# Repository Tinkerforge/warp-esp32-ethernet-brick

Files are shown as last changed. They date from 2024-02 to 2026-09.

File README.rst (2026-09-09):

WARP ESP32 Ethernet Brick
=========================

This repository contains the firmware source code and the hardware design
files. The documentation generator configs can be found at
https://github.com/Tinkerforge/generators

.. BEGIN WARP REPOSITORIES (managed block, generated from esp32-firmware/repo_overview.rst - do not edit by hand, run update_repo_overview.py instead)

WARP Repositories
-----------------

This is an overview of all repositories that make up the WARP Charger and
WARP Energy Manager ecosystem.

Please report **any** issue concerning WARP hard- or software in the
`esp32-firmware`_ repository, no matter which repository it originates from.

Software
~~~~~~~~

- `esp32-firmware`_ - Source code of the ESP32 firmware shared between all WARP Chargers and Energy Managers

Libraries used by the firmware:

- `tfjson`_ - SAX style JSON serializer and deserializer
- `tfnetwork`_ - Modbus TCP server and client implementation
- `tfocpp`_ - OCPP 1.6 implementation
- `tftools`_ - Miscellaneous tools and helpers

Remote access:

- `esp32-remote-access`_ - Source code of the my.warp-charger.com remote access server

Documentation, tools and integrations:

- `warp-charger`_ - Source code of (docs.)warp-charger.com and the printed manual, released firmwares, datasheets and documents, as well as some tools and hardware design files
- `api.warp-charger.com`_ - Serves APIs that are used by WARP Chargers to obtain relevant public information like day ahead prices
- `vislog.warp-charger.com`_ - Visualizes WARP Charger logs and EVSE debug protocols
- `dbus-warp-charger`_ - Integrates WARP Chargers into a Victron Energy Venus OS device (e.g. Cerbo GX)

WARP Charger Hardware
~~~~~~~~~~~~~~~~~~~~~~

WARP4 Charger
"""""""""""""

*Current charger generation.*

- `warp-esp32-ethernet-v2-brick`_ - Hardware design files of the WARP ESP32 Ethernet Brick 2.0
- `warp-esp32-ethernet-v2-co-bricklet`_ - Firmware source code of the WARP ESP32 Ethernet 2.0 Co Bricklet (co-processor)
- `evse-v4-bricklet`_ - Hardware design files of the EVSE 4.0 Bricklet (firmware shared with the EVSE 2.0 Bricklet)
- `nfc-bricklet`_ - Firmware source code and hardware design files of the NFC Bricklet

WARP3 Charger
"""""""""""""

- `warp-esp32-ethernet-brick`_ - Hardware design files of the WARP ESP32 Ethernet Brick
- `evse-v3-bricklet`_ - Hardware design files of the EVSE 3.0 Bricklet (firmware shared with the EVSE 2.0 Bricklet)
- `nfc-bricklet`_ - Firmware source code and hardware design files of the NFC Bricklet

WARP2 Charger
"""""""""""""

- `esp32-ethernet-brick`_ - Hardware design files of the ESP32 Ethernet Brick
- `evse-v2-bricklet`_ - Firmware source code and hardware design files of the EVSE 2.0 Bricklet
- `nfc-bricklet`_ - Firmware source code and hardware design files of the NFC Bricklet

WARP1 Charger
"""""""""""""

- `esp32-brick`_ - Hardware design files of the ESP32 Brick
- `evse-bricklet`_ - Firmware source code and hardware design files of the EVSE Bricklet
- `rs485-bricklet`_ - Firmware source code and hardware design files of the RS485 Bricklet

WARP Energy Manager Hardware
~~~~~~~~~~~~~~~~~~~~~~~~~~~~~~

WARP Energy Manager 2.0
"""""""""""""""""""""""

*Current energy manager generation.*

- `esp32-ethernet-brick`_ - Hardware design files of the ESP32 Ethernet Brick
- `warp-energy-manager-v2-bricklet`_ - Firmware source code and hardware design files of the WARP Energy Manager 2.0 Bricklet
- `warp-front-panel-bricklet`_ - Firmware source code and hardware design files of the WARP Front Panel Bricklet

WARP Energy Manager 1.0
"""""""""""""""""""""""

- `esp32-ethernet-brick`_ - Hardware design files of the ESP32 Ethernet Brick
- `warp-energy-manager-bricklet`_ - Firmware source code and hardware design files of the WARP Energy Manager Bricklet

Forked/patched projects
~~~~~~~~~~~~~~~~~~~~~~~~~

- `arduino-esp32`_
- `esp32-arduino-libs`_
- `WireGuard-ESP32-Arduino`_

.. Link targets: One definition per repository, keep in sync with the lists above.

.. _esp32-firmware: https://github.com/Tinkerforge/esp32-firmware
.. _tfjson: https://github.com/Tinkerforge/tfjson
.. _tfnetwork: https://github.com/Tinkerforge/tfnetwork
.. _tfocpp: https://github.com/Tinkerforge/tfocpp
.. _tftools: https://github.com/Tinkerforge/tftools
.. _esp32-remote-access: https://github.com/Tinkerforge/esp32-remote-access
.. _warp-charger: https://github.com/Tinkerforge/warp-charger
.. _api.warp-charger.com: https://github.com/Tinkerforge/api.warp-charger.com
.. _vislog.warp-charger.com: https://github.com/Tinkerforge/vislog.warp-charger.com
.. _dbus-warp-charger: https://github.com/Tinkerforge/dbus-warp-charger
.. _warp-esp32-ethernet-v2-brick: https://github.com/Tinkerforge/warp-esp32-ethernet-v2-brick
.. _warp-esp32-ethernet-v2-co-bricklet: https://github.com/Tinkerforge/warp-esp32-ethernet-v2-co-bricklet
.. _evse-v4-bricklet: https://github.com/Tinkerforge/evse-v4-bricklet
.. _nfc-bricklet: https://github.com/Tinkerforge/nfc-bricklet
.. _warp-esp32-ethernet-brick: https://github.com/Tinkerforge/warp-esp32-ethernet-brick
.. _evse-v3-bricklet: https://github.com/Tinkerforge/evse-v3-bricklet
.. _esp32-ethernet-brick: https://github.com/Tinkerforge/esp32-ethernet-brick
.. _evse-v2-bricklet: https://github.com/Tinkerforge/evse-v2-bricklet
.. _esp32-brick: https://github.com/Tinkerforge/esp32-brick
.. _evse-bricklet: https://github.com/Tinkerforge/evse-bricklet
.. _rs485-bricklet: https://github.com/Tinkerforge/rs485-bricklet
.. _warp-energy-manager-v2-bricklet: https://github.com/Tinkerforge/warp-energy-manager-v2-bricklet
.. _warp-front-panel-bricklet: https://github.com/Tinkerforge/warp-front-panel-bricklet
.. _warp-energy-manager-bricklet: https://github.com/Tinkerforge/warp-energy-manager-bricklet
.. _arduino-esp32: https://github.com/Tinkerforge/arduino-esp32
.. _esp32-arduino-libs: https://github.com/Tinkerforge/esp32-arduino-libs
.. _WireGuard-ESP32-Arduino: https://github.com/Tinkerforge/WireGuard-ESP32-Arduino

.. END WARP REPOSITORIES

Repository Content
------------------

hardware/:
 * Contains KiCad project files and additionally schematics as PDF

datasheets/:
 * Contains datasheets for sensors and complex ICs that are used

Hardware
--------

The hardware is designed with the open source EDA Suite KiCad
(http://www.kicad.org). Before you are able to open the files,
you have to install the Tinkerforge kicad-libraries
(https://github.com/Tinkerforge/kicad-libraries). You can either clone
them directly in hardware/ or clone them in a separate folder and
symlink them into hardware/
(ln -s kicad_path/kicad-libraries project_path/hardware). After that you
can open the .pro file in hardware/ with KiCad and from there view and
modify the schematics and the PCB layout.

Software
--------

The software for all Bricks based on the ESP32 can be found at:
https://github.com/Tinkerforge/esp32-firmware/tree/master/software

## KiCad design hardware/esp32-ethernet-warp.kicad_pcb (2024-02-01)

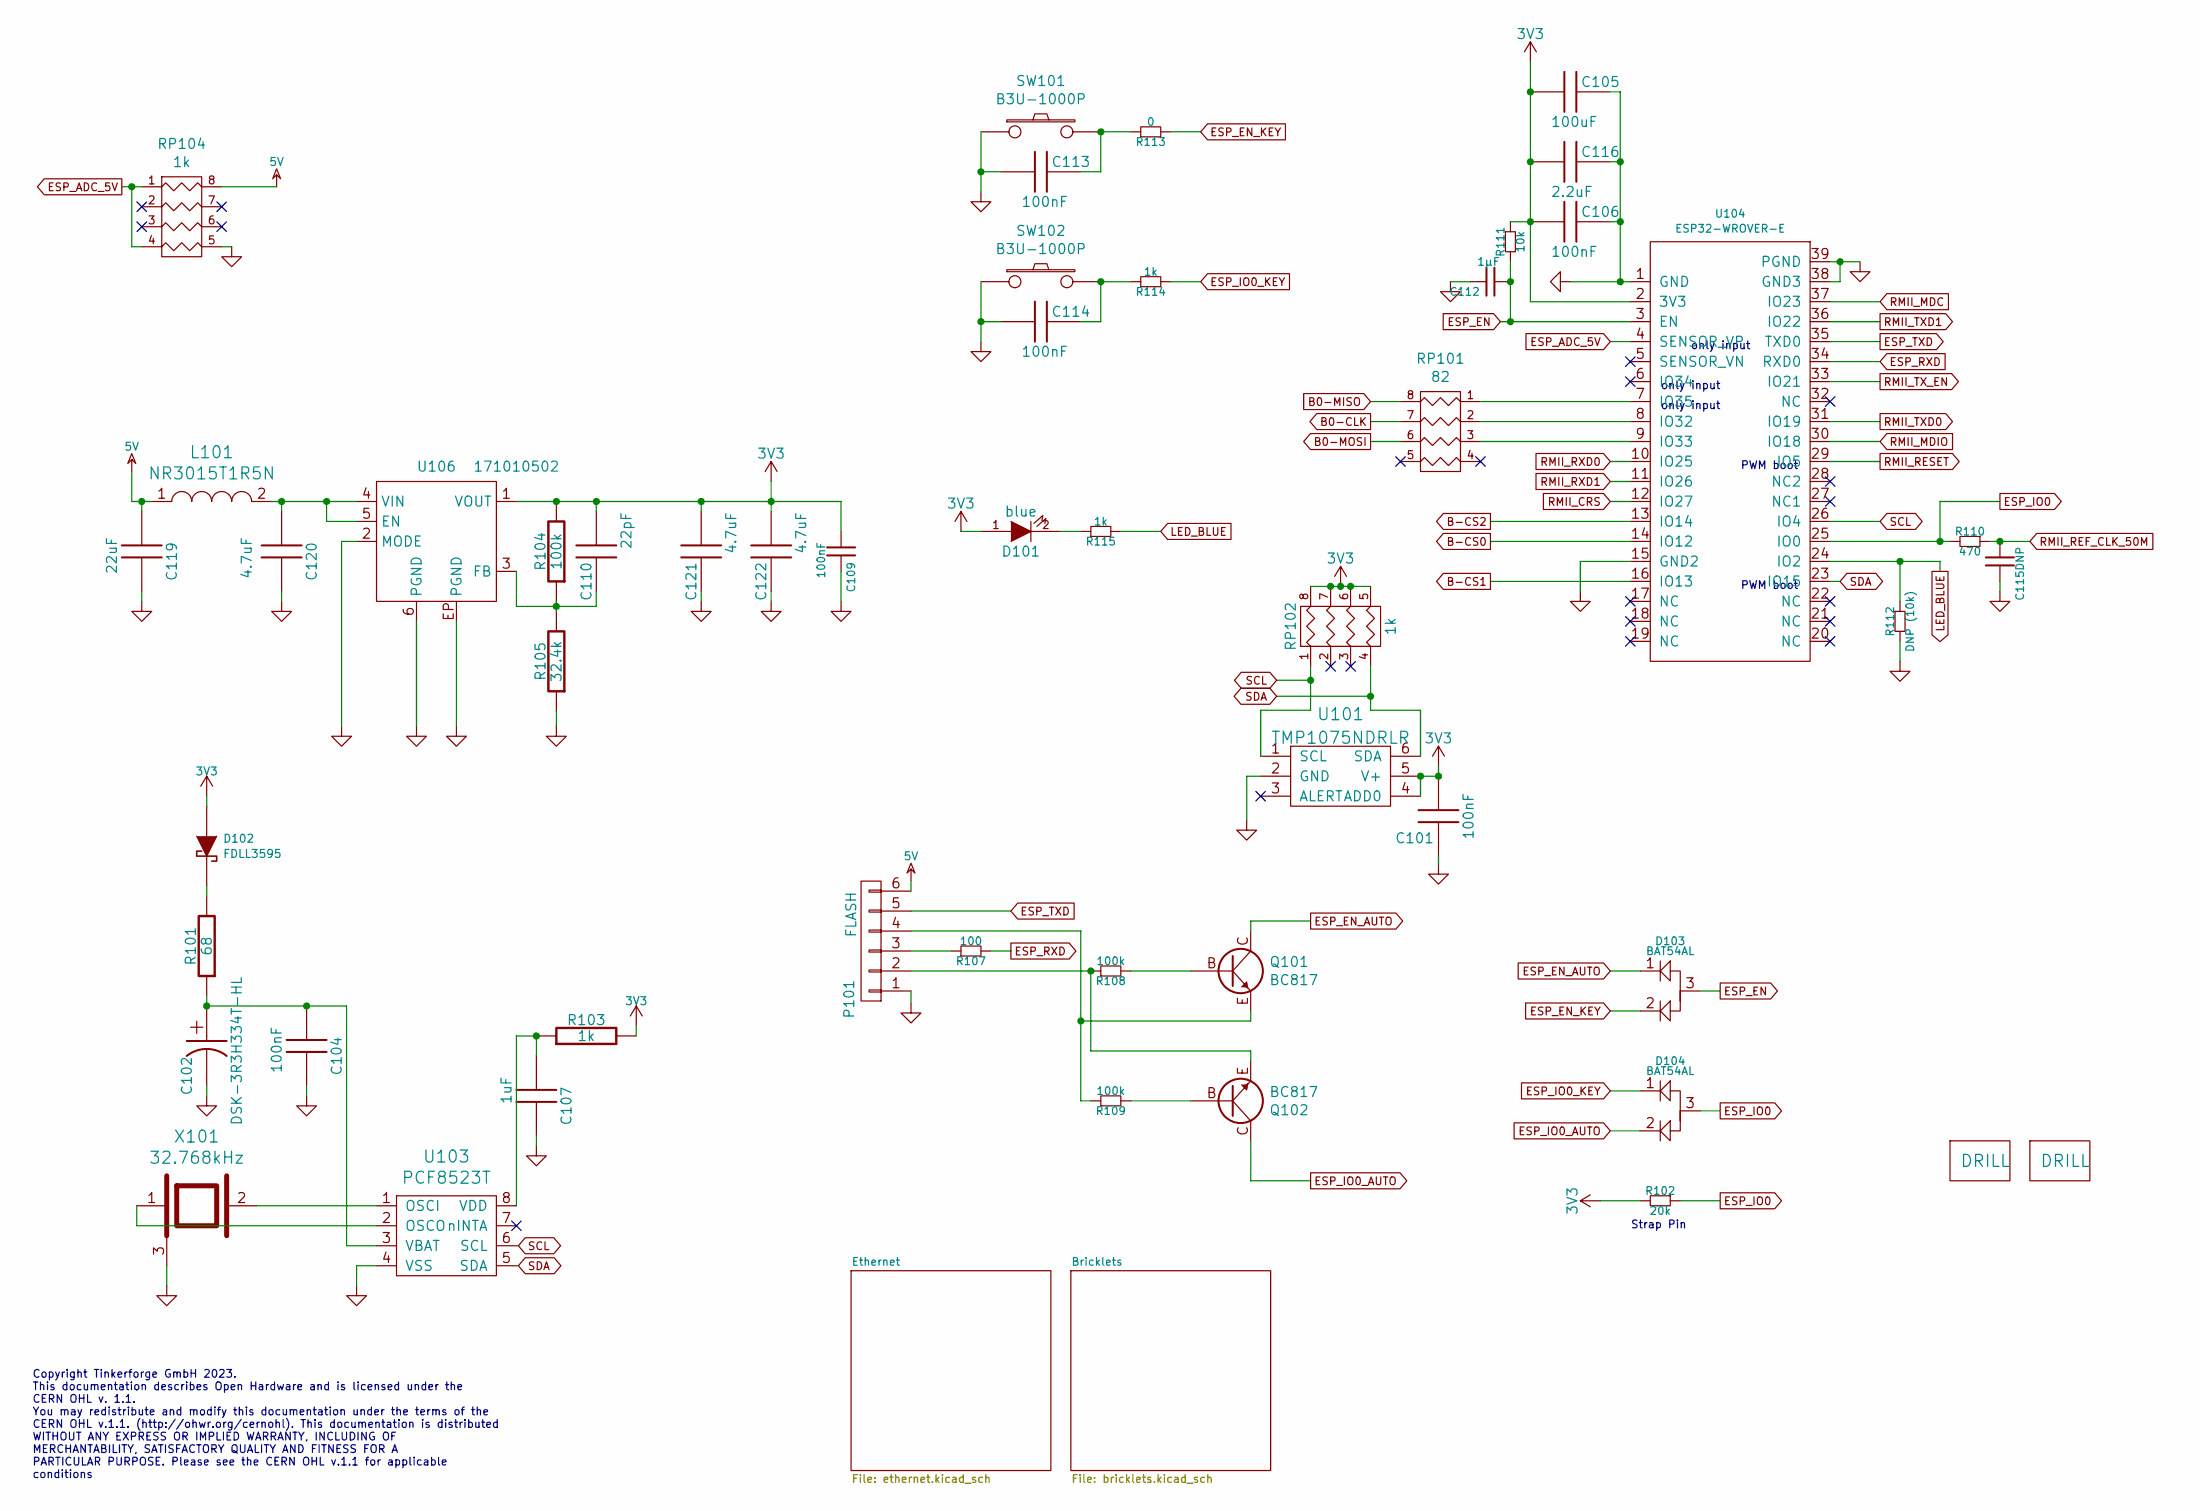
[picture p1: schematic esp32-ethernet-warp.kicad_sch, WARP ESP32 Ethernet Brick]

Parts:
C101, C104, C106, C109, C113, C114: 100nF; C0402F
C102: DSK-3R3H334T-HL; DSK
C105: 100uF; C1210
C107: 1uF; C0603F
C110: 22pF; C0402F
C112: 1µF; C0603F
C115: DNP; C0402F
C116: 2.2uF; C0603F
C119: 22uF; C1206
C120, C121, C122: 4.7uF; C0805E
D101: blue; D0603F
D102: FDLL3595; MiniMelf
D103, D104: BAT54AL; SOT23-3
F102, F103: DRILL; LSMTSO-M3
L101: NR3015T1R5N; NR3030
P101: FLASH; pin_array_1x6-P2mm_D1mm
Q101, Q102: BC817; SOT23EBC
R101: 68; R0402F
R102: 20k; R0402F
R103, R114, R115: 1k; R0402F
R104, R108, R109: 100k; R0402F
R105: 32.4k; R0402F
R107: 100; R0402F
R110: 470; R0402F
R111: 10k; R0402F
R112: DNP (10k); R0402F
R113: 0; R0402F
RP101: 82; 4X0402
RP102, RP104: 1k; 4X0402
SW101, SW102: B3U-1000P
U101: TMP1075NDRLR; SOT563
U103: PCF8523T; SO-8
U104: ESP32-WROVER-E
U106: 171010502
X101: 32.768kHz; AB26TRQ

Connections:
3V3: C101.1, C105.2, C106.2, C109.2, C110.2, C116.2, C121.2, C122.2, D101.1 (A), D102.1 (A), R102.2, R103.2, R104.2, R111.1, RP102.5 (R4), RP102.6 (R3), RP102.7 (R2), RP102.8 (R1), U101.4 (ADD0), U101.5 (V+), U104.2 (3V3), U106.1 (VOUT); also elsewhere on the board
5V: C119.2, L101.1, P101.6, RP104.8 (R1); also elsewhere on the board
B0-CLK: RP101.7 (R2); also elsewhere on the board
B0-MISO: RP101.8 (R1); also elsewhere on the board
B0-MOSI: RP101.6 (R3); also elsewhere on the board
B-CS0: U104.14 (IO12); also elsewhere on the board
B-CS1: U104.16 (IO13); also elsewhere on the board
B-CS2: U104.13 (IO14); also elsewhere on the board
ESP_ADC_5V: RP104.1, RP104.4, U104.4 (SENSOR_VP)
ESP_EN: C112.2, D103.3, R111.2, U104.3 (EN)
ESP_EN_AUTO: D103.1, Q101.C
ESP_EN_KEY: D103.2, R113.2
ESP_IO0: D104.3, R102.1, R110.2, U104.25 (IO0)
ESP_IO0_AUTO: D104.2, Q102.C
ESP_IO0_KEY: D104.1, R114.2
ESP_RXD: R107.2, U104.34 (RXD0)
ESP_TXD: P101.5, U104.35 (TXD0)
GND: C101.2, C102.2, C104.1, C105.1, C106.1, C107.1, C109.1, C112.1, C113.2, C114.2, C115.2, C116.1, C119.1, C120.1, C121.1, C122.1, P101.1, R105.1, R112.2, RP104.5 (R4), SW101.1, SW102.1, U101.2 (GND), U103.4 (VSS), U104.1 (GND), U104.15 (GND2), U104.38 (GND3), U104.39 (PGND), U106.2 (MODE), U106.6 (PGND), U106.EP (PGND), X101.3; also elsewhere on the board
LED_BLUE: R112.1, R115.2, U104.24 (IO2)
unnamed: C113.1, R113.1, SW101.2
unnamed: C114.1, R114.1, SW102.2
unnamed: D101.2 (K), R115.1
unnamed: D102.2 (K), R101.2
unnamed: P101.2, Q102.E, R108.1
unnamed: P101.3, R107.1
unnamed: P101.4, Q101.E, R109.1
unnamed: Q101.B, R108.2
unnamed: Q102.B, R109.2
unnamed: RP101.1, U104.7 (IO35)
unnamed: RP101.2, U104.8 (IO32)
unnamed: RP101.3, U104.9 (IO33)
unnamed: U103.1 (OSCI), X101.2
unnamed: U103.2 (OSCO), X101.1
unnamed: C102.1, C104.2, R101.1, U103.3 (VBAT)
unnamed: C107.2, R103.1, U103.8 (VDD)
unnamed: C120.2, L101.2, U106.4 (VIN), U106.5 (EN)
unnamed: C110.1, R104.1, R105.2, U106.3 (FB)
RMII_CRS: U104.12 (IO27); also elsewhere on the board
RMII_MDC: U104.37 (IO23); also elsewhere on the board
RMII_MDIO: U104.30 (IO18); also elsewhere on the board
RMII_REF_CLK_50M: C115.1, R110.1; also elsewhere on the board
RMII_RESET: U104.29 (IO5); also elsewhere on the board
RMII_RXD0: U104.10 (IO25); also elsewhere on the board
RMII_RXD1: U104.11 (IO26); also elsewhere on the board
RMII_TXD0: U104.31 (IO19); also elsewhere on the board
RMII_TXD1: U104.36 (IO22); also elsewhere on the board
RMII_TX_EN: U104.33 (IO21); also elsewhere on the board
SCL: RP102.1, U101.1 (SCL), U103.6 (SCL), U104.26 (IO4)
SDA: RP102.4, U101.6 (SDA), U103.5 (SDA), U104.23 (IO15)

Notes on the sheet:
Strap Pin
only input
Copyright Tinkerforge GmbH 2023. This documentation describes Open Hardware and is licensed under the CERN OHL v. 1.1. You may redistribute and modify this documentation under the terms of the CERN OHL v.1.1. (http://ohwr.org/cernohl). This documentation is distributed WITHOUT ANY EXPRESS OR IMPLIE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
PWM boot

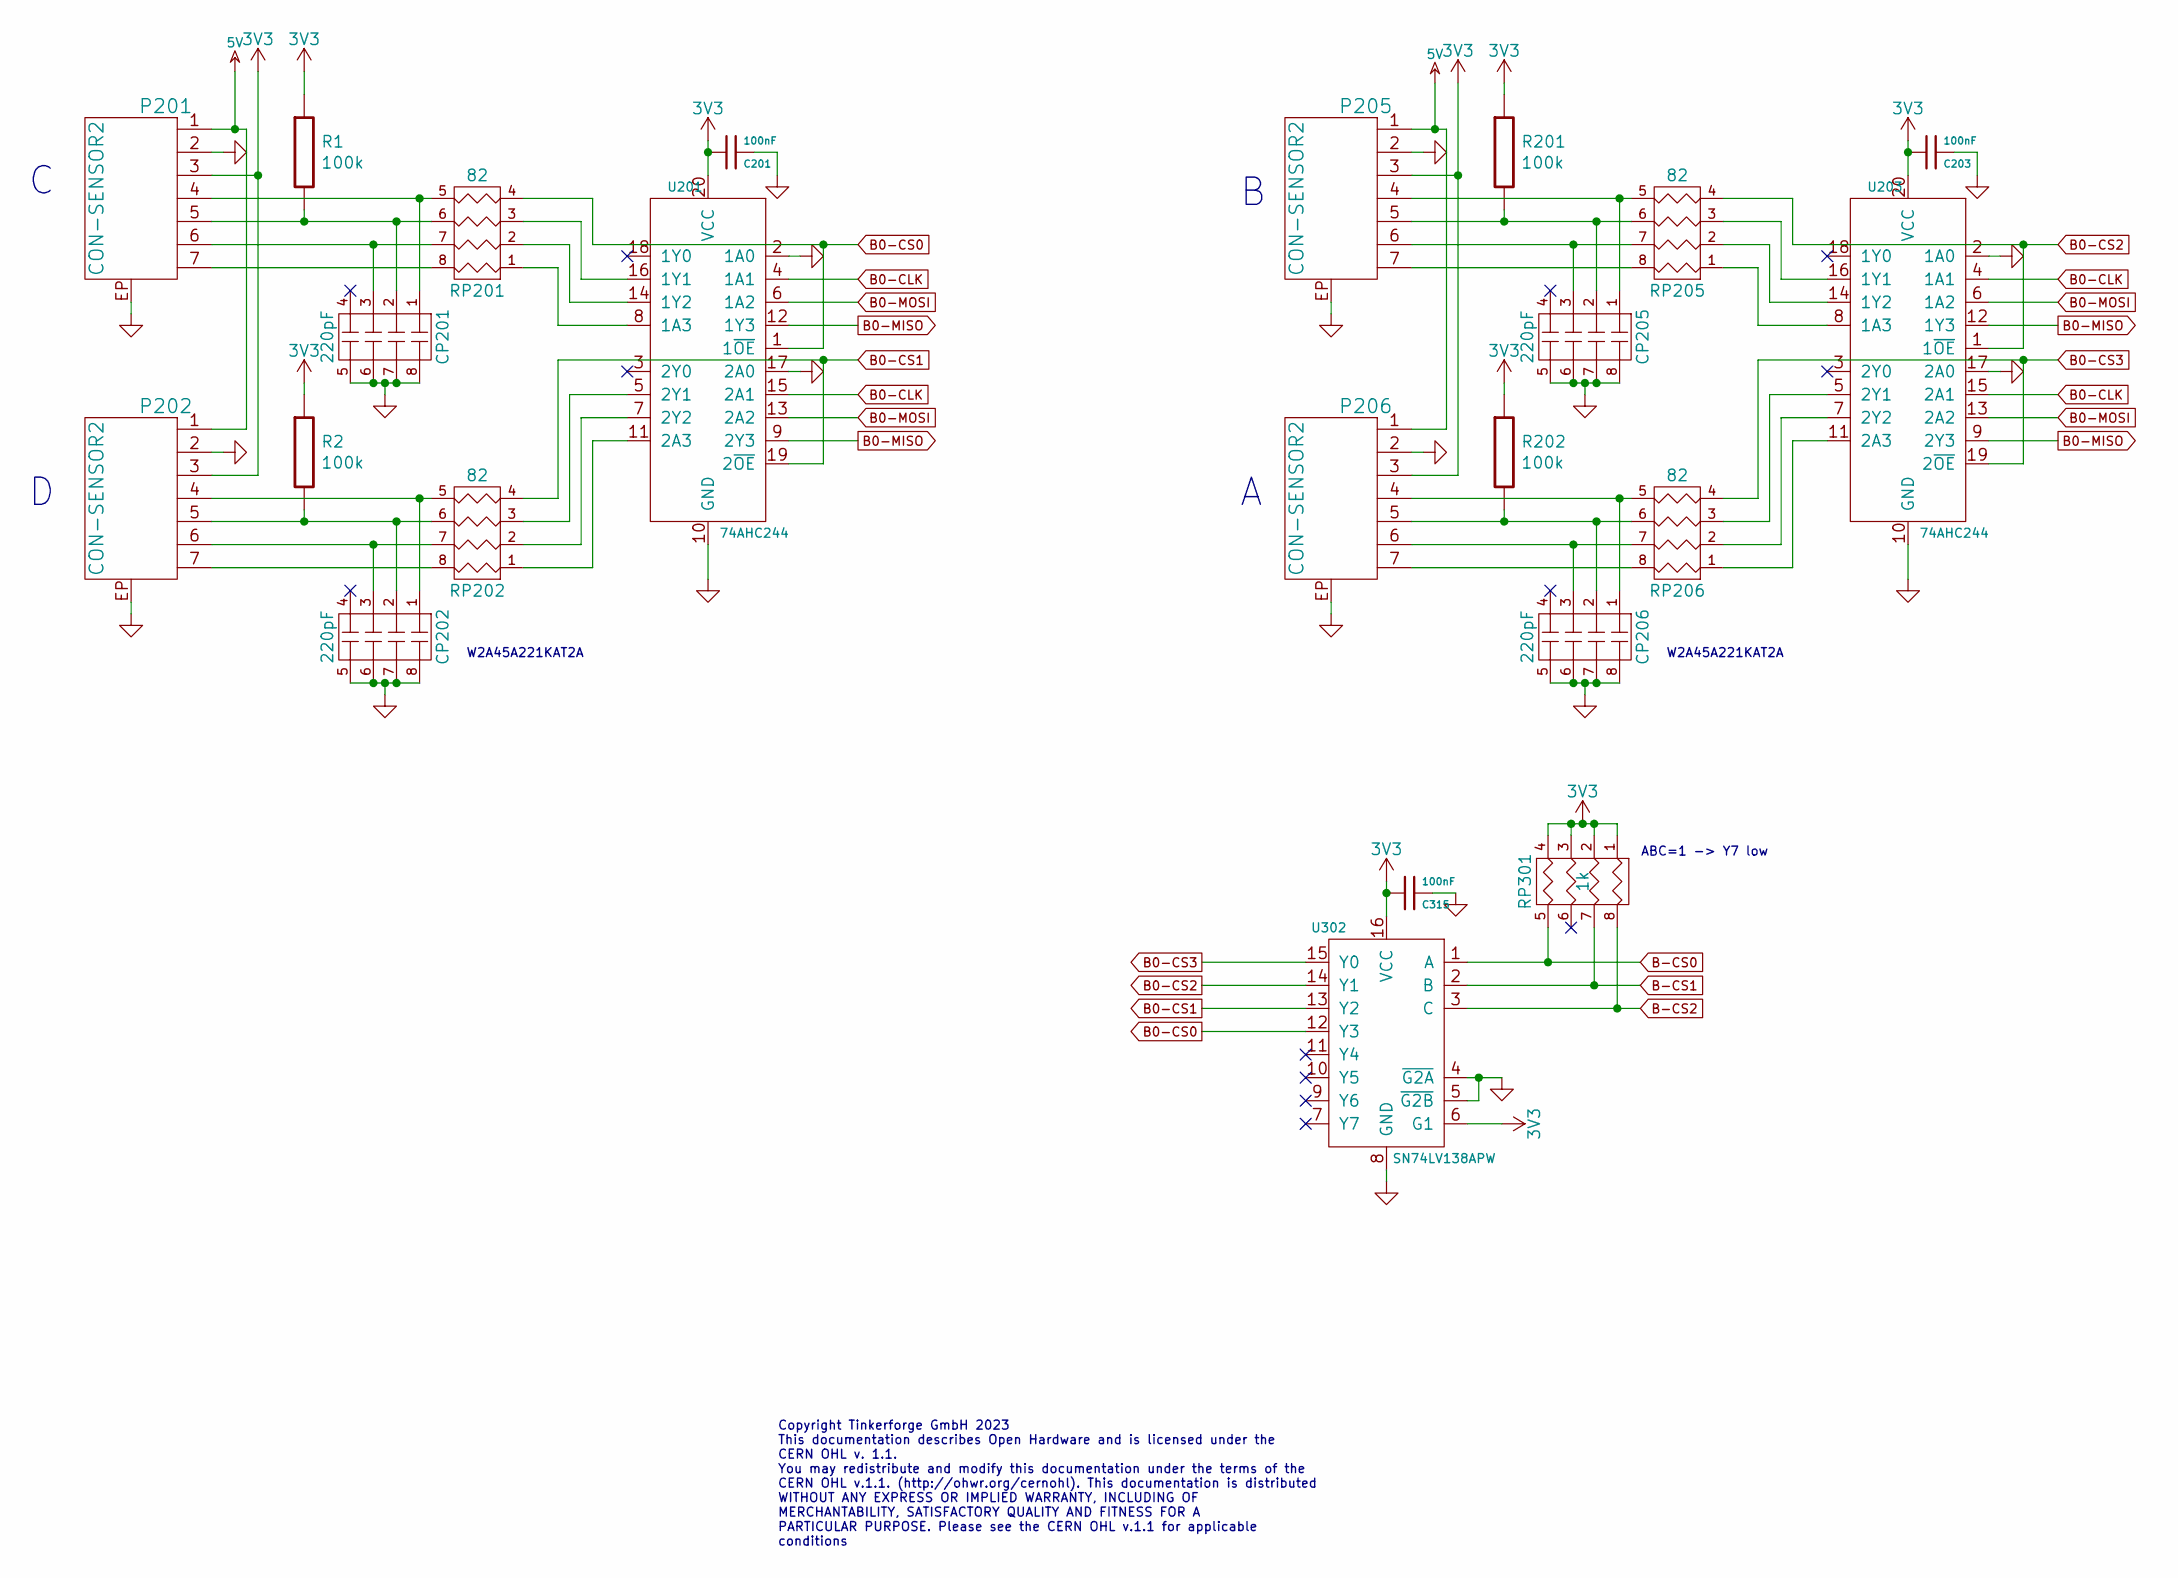
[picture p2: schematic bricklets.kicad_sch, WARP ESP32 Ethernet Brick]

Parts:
C201, C203, C315: 100nF; C0402F
CP201, CP202, CP205, CP206: 220pF; 4X0402
P201, P202, P205, P206: CON-SENSOR2
R1, R2, R201, R202: 100k; R0402F
RP201, RP202, RP205, RP206: 82; 4X0402
RP301: 1k; 4X0402
U201, U203: 74AHC244; TSSOP20
U302: SN74LV138APW; TSSOP16

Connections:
3V3: C201.2, C203.2, C315.2, P201.3, P202.3, P205.3, P206.3, R1.1, R2.1, R201.1, R202.1, RP301.1, RP301.2, RP301.3, RP301.4, U201.20 (VCC), U203.20 (VCC), U302.6 (G1), U302.16 (VCC); also elsewhere on the board
5V: P201.1, P202.1, P205.1, P206.1; also elsewhere on the board
B0-CLK: U201.4 (1A1), U201.15 (2A1), U203.4 (1A1), U203.15 (2A1); also elsewhere on the board
B0-CS0: RP201.4, U201.1 (1~OE), U302.12 (Y3)
B0-CS1: RP202.4, U201.19 (2~OE), U302.13 (Y2)
B0-CS2: RP205.4, U203.1 (1~OE), U302.14 (Y1)
B0-CS3: RP206.4, U203.19 (2~OE), U302.15 (Y0)
B0-MISO: U201.9 (2Y3), U201.12 (1Y3), U203.9 (2Y3), U203.12 (1Y3); also elsewhere on the board
B0-MOSI: U201.6 (1A2), U201.13 (2A2), U203.6 (1A2), U203.13 (2A2); also elsewhere on the board
B-CS0: RP301.5 (R4), U302.1 (A); also elsewhere on the board
B-CS1: RP301.7 (R2), U302.2 (B); also elsewhere on the board
B-CS2: RP301.8 (R1), U302.3 (C); also elsewhere on the board
GND: C201.1, C203.1, C315.1, CP201.5 (R4), CP201.6 (R3), CP201.7 (R2), CP201.8 (R1), CP202.5 (R4), CP202.6 (R3), CP202.7 (R2), CP202.8 (R1), CP205.5 (R4), CP205.6 (R3), CP205.7 (R2), CP205.8 (R1), CP206.5 (R4), CP206.6 (R3), CP206.7 (R2), CP206.8 (R1), P201.2, P201.EP, P202.2, P202.EP, P205.2, P205.EP, P206.2, P206.EP, U201.2 (1A0), U201.10 (GND), U201.17 (2A0), U203.2 (1A0), U203.10 (GND), U203.17 (2A0), U302.4 (~G2A), U302.5 (~G2B), U302.8 (GND); also elsewhere on the board
unnamed: CP201.1, P201.4, RP201.5 (R4)
unnamed: CP201.2, P201.5, R1.2, RP201.6 (R3)
unnamed: CP201.3, P201.6, RP201.7 (R2)
unnamed: CP202.1, P202.4, RP202.5 (R4)
unnamed: CP202.2, P202.5, R2.2, RP202.6 (R3)
unnamed: CP202.3, P202.6, RP202.7 (R2)
unnamed: CP205.1, P205.4, RP205.5 (R4)
unnamed: CP205.2, P205.5, R201.2, RP205.6 (R3)
unnamed: CP205.3, P205.6, RP205.7 (R2)
unnamed: CP206.1, P206.4, RP206.5 (R4)
unnamed: CP206.2, P206.5, R202.2, RP206.6 (R3)
unnamed: CP206.3, P206.6, RP206.7 (R2)
unnamed: RP201.1, U201.8 (1A3)
unnamed: RP201.2, U201.14 (1Y2)
unnamed: RP201.3, U201.16 (1Y1)
unnamed: P201.7, RP201.8 (R1)
unnamed: RP202.1, U201.11 (2A3)
unnamed: RP202.2, U201.7 (2Y2)
unnamed: RP202.3, U201.5 (2Y1)
unnamed: P202.7, RP202.8 (R1)
unnamed: RP205.1, U203.8 (1A3)
unnamed: RP205.2, U203.14 (1Y2)
unnamed: RP205.3, U203.16 (1Y1)
unnamed: P205.7, RP205.8 (R1)
unnamed: RP206.1, U203.11 (2A3)
unnamed: RP206.2, U203.7 (2Y2)
unnamed: RP206.3, U203.5 (2Y1)
unnamed: P206.7, RP206.8 (R1)

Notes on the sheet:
Copyright Tinkerforge GmbH 2023 This documentation describes Open Hardware and is licensed under the CERN OHL v. 1.1. You may redistribute and modify this documentation under the terms of the CERN OHL v.1.1. (http://ohwr.org/cernohl). This documentation is distributed WITHOUT ANY EXPRESS OR IMPLIED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
W2A45A221KAT2A
ABC=1 -> Y7 low

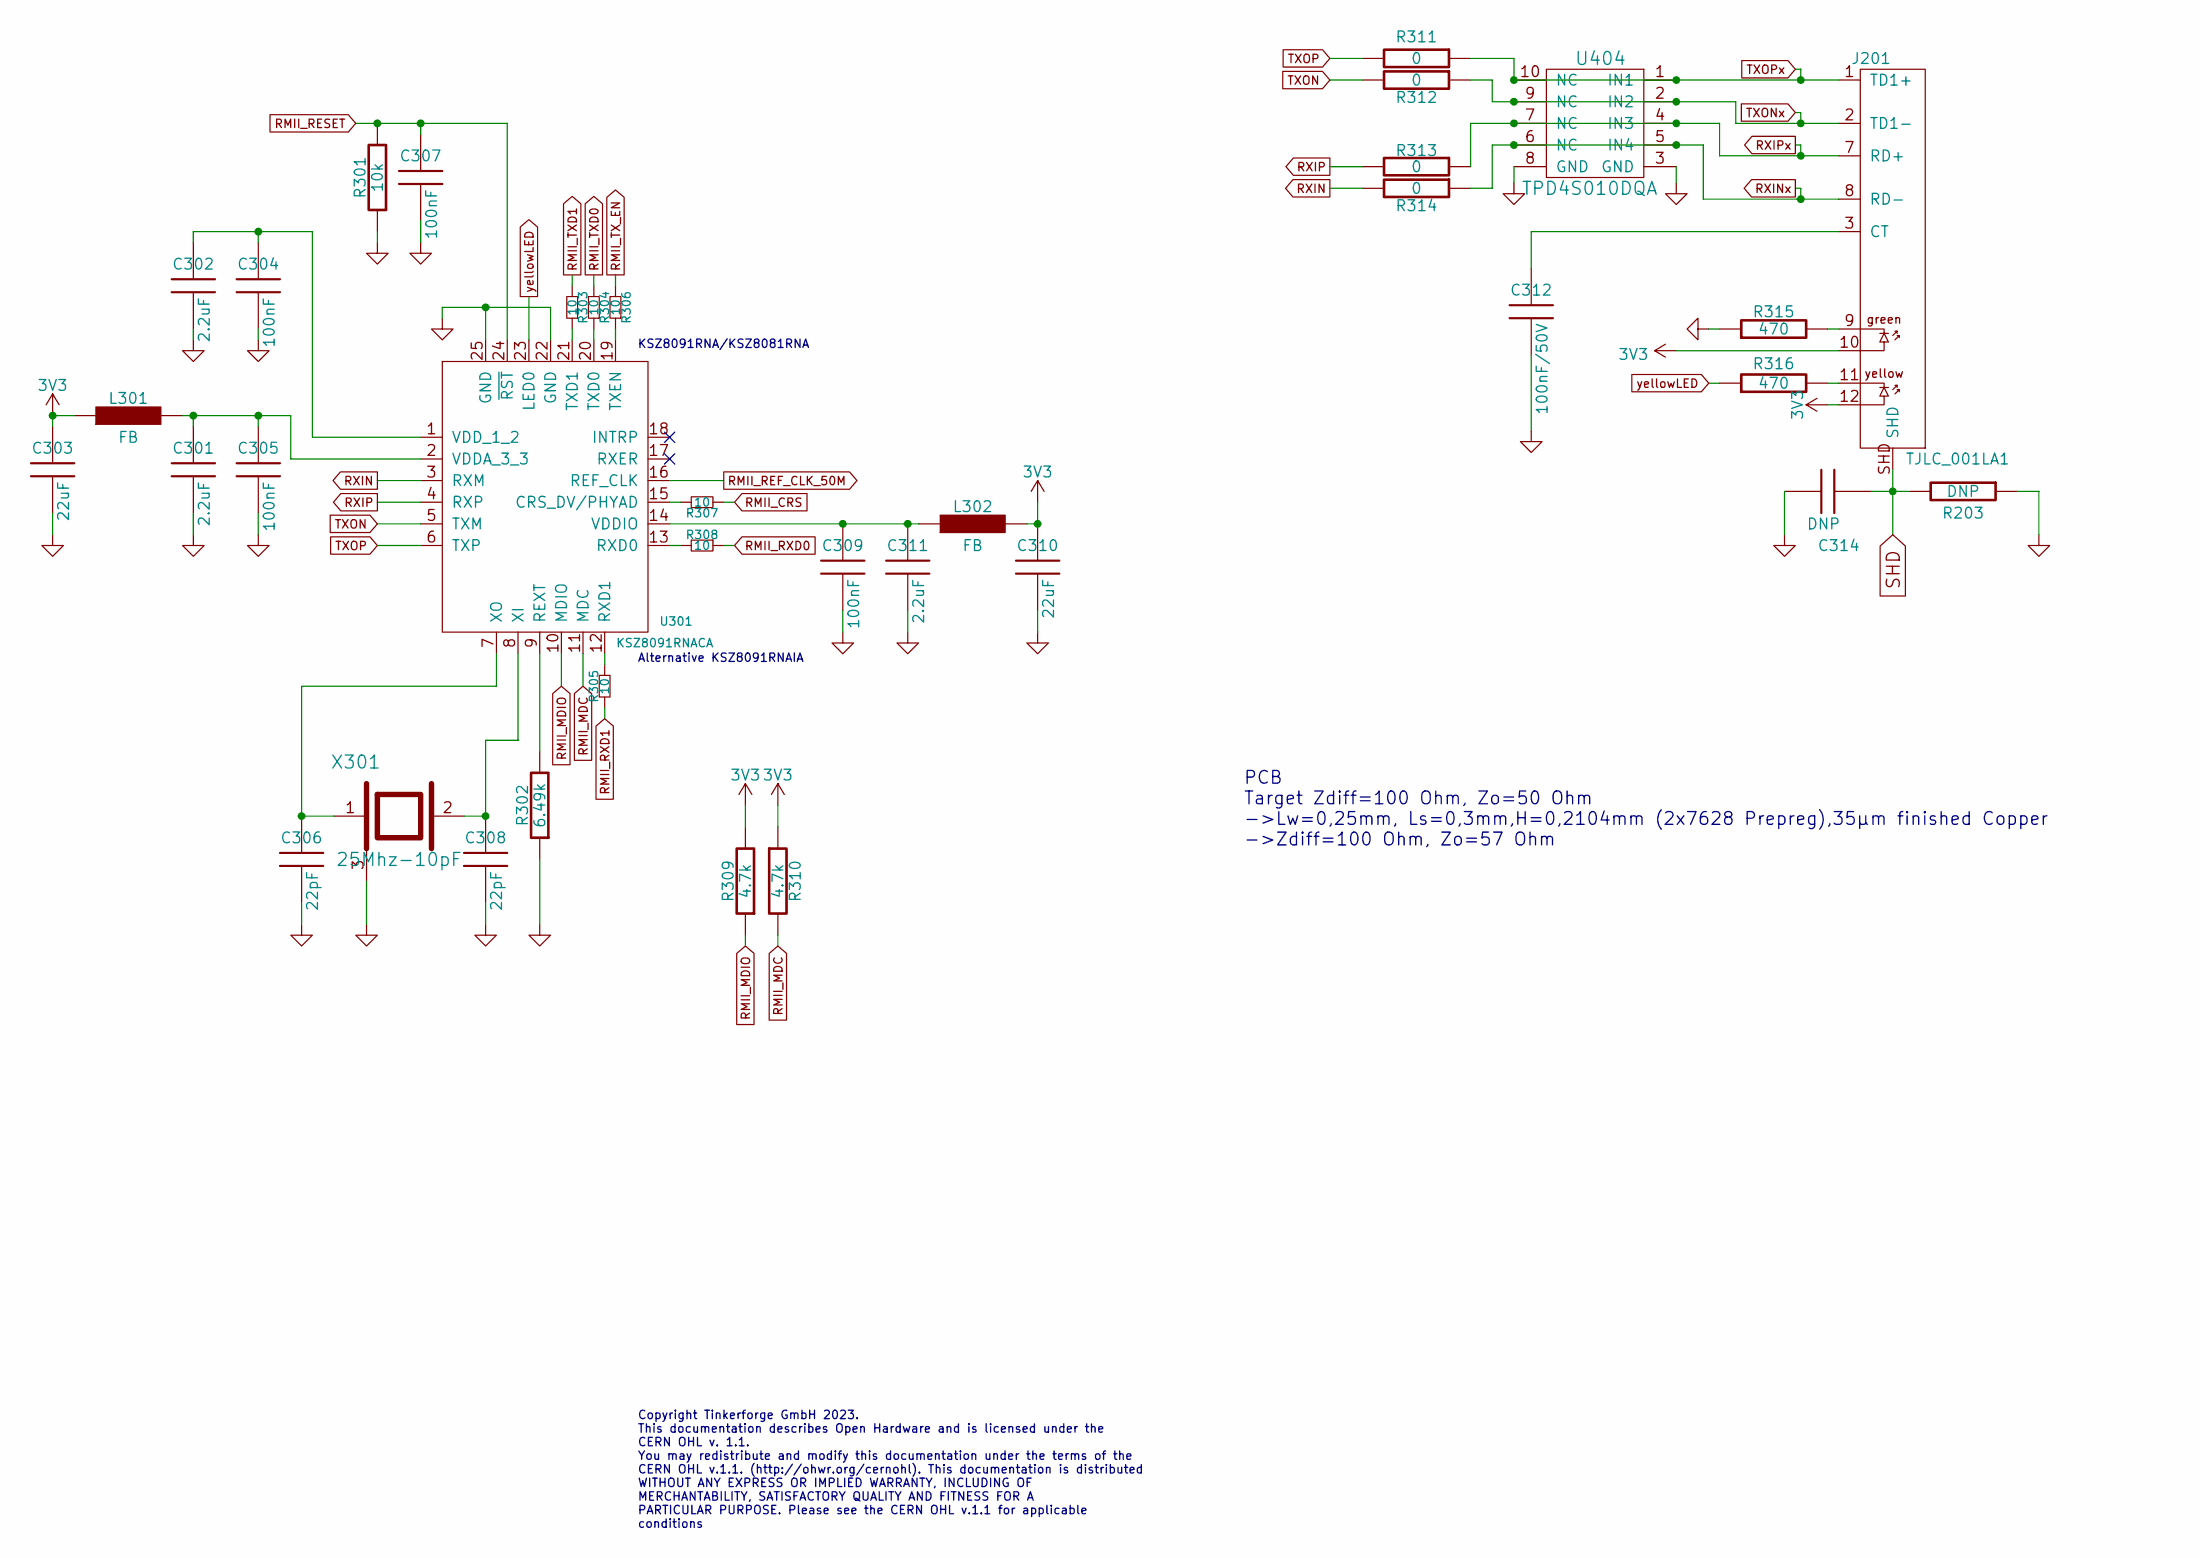
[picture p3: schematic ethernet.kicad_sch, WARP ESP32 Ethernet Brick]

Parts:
C301, C302, C311: 2.2uF; C0603F
C303, C310: 22uF; C1206
C304, C305, C307, C309: 100nF; C0402F
C306, C308: 22pF; C0402F
C312: 100nF/50V; C0402F
C314: DNP; C1206
J201: TJLC_001LA1; TJLC-001LA1
L301, L302: FB; R0603F
R203: DNP; 1812
R301: 10k; R0402F
R302: 6.49k; R0402F
R303, R304, R305, R306, R307, R308: 10; R0402F
R309, R310: 4.7k; R0402F
R311, R312, R313, R314: 0; R0402F
R315, R316: 470; R0402F
U301: KSZ8091RNACA; QFN-24-4x4-EP
U404: TPD4S010DQA
X301: 25Mhz-10pF; CRYSTAL_3225

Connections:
3V3: C303.2, C310.2, J201.10, J201.12, L301.1, L302.2, R309.2, R310.1; also elsewhere on the board
GND: C301.1, C302.1, C303.1, C304.1, C305.1, C306.1, C307.1, C308.1, C309.1, C310.1, C311.1, C312.1, C314.2, R203.1, R301.1, R302.1, R315.1, U301.22 (GND), U301.25 (GND), X301.3; also elsewhere on the board
unnamed: C312.2, J201.3 (CT)
unnamed: J201.9, R315.2
unnamed: J201.11, R316.2
unnamed: R307.1, U301.15 (CRS_DV/PHYAD)
unnamed: R302.2, U301.9 (REXT)
unnamed: R308.2, U301.13 (RXD0)
unnamed: R305.1, U301.12 (RXD1)
unnamed: R304.1, U301.20 (TXD0)
unnamed: R303.1, U301.21 (TXD1)
unnamed: R306.1, U301.19 (TXEN)
unnamed: C301.2, C305.2, L301.2, U301.2 (VDDA_3_3)
unnamed: C309.2, C311.2, L302.1, U301.14 (VDDIO)
unnamed: C302.2, C304.2, U301.1 (VDD_1_2)
unnamed: C308.2, U301.8 (XI), X301.2
unnamed: C306.2, U301.7 (XO), X301.1
RMII_CRS: R307.2; also elsewhere on the board
RMII_MDC: R310.2, U301.11 (MDC); also elsewhere on the board
RMII_MDIO: R309.1, U301.10 (MDIO); also elsewhere on the board
RMII_REF_CLK_50M: U301.16 (REF_CLK); also elsewhere on the board
RMII_RESET: C307.2, R301.2, U301.24 (~RST); also elsewhere on the board
RMII_RXD0: R308.1; also elsewhere on the board
RMII_RXD1: R305.2; also elsewhere on the board
RMII_TXD0: R304.2; also elsewhere on the board
RMII_TXD1: R303.2; also elsewhere on the board
RMII_TX_EN: R306.2; also elsewhere on the board
RXIN: R314.2, U301.3 (RXM)
RXINx: J201.8 (RD-), R314.1; also elsewhere on the board
RXIP: R313.2, U301.4 (RXP)
RXIPx: J201.7 (RD+), R313.1; also elsewhere on the board
SHD: C314.1, J201.SHD, R203.2
TXON: R312.2, U301.5 (TXM)
TXONx: J201.2 (TD1-), R312.1; also elsewhere on the board
TXOP: R311.2, U301.6 (TXP)
TXOPx: J201.1 (TD1+), R311.1; also elsewhere on the board
yellowLED: R316.1, U301.23 (LED0)

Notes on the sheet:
KSZ8091RNA/KSZ8081RNA
PCB Target Zdiff=100 Ohm, Zo=50 Ohm ->Lw=0,25mm, Ls=0,3mm,H=0,2104mm (2x7628 Prepreg),35µm finished Copper ->Zdiff=100 Ohm, Zo=57 Ohm
Alternative KSZ8091RNAIA
Copyright Tinkerforge GmbH 2023. This documentation describes Open Hardware and is licensed under the CERN OHL v. 1.1. You may redistribute and modify this documentation under the terms of the CERN OHL v.1.1. (http://ohwr.org/cernohl). This documentation is distributed WITHOUT ANY EXPRESS OR IMPLIE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

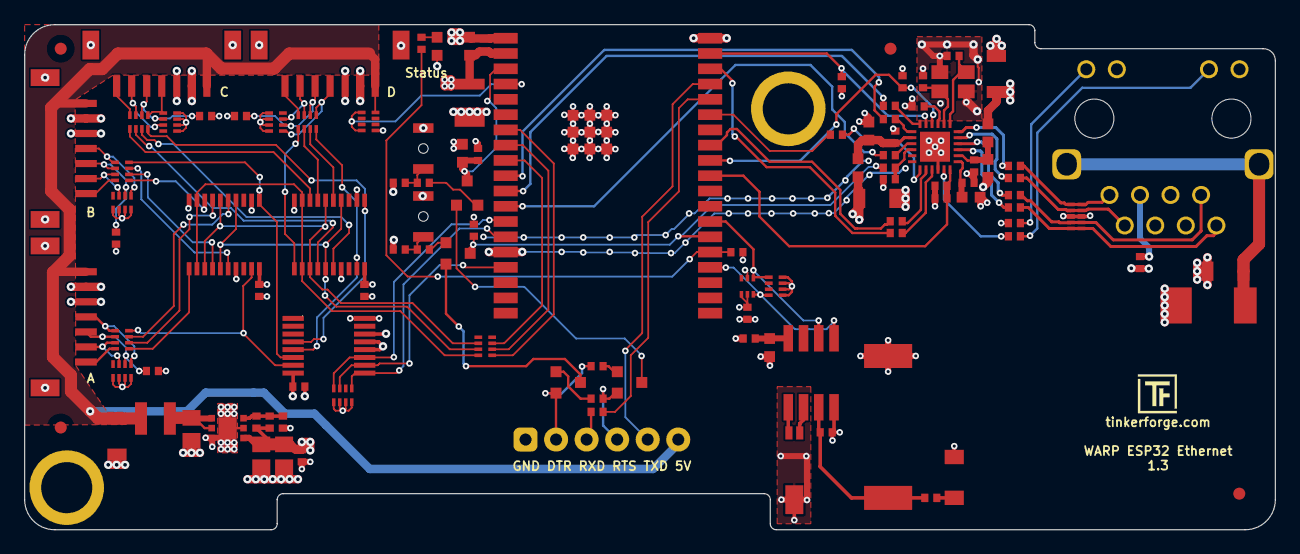
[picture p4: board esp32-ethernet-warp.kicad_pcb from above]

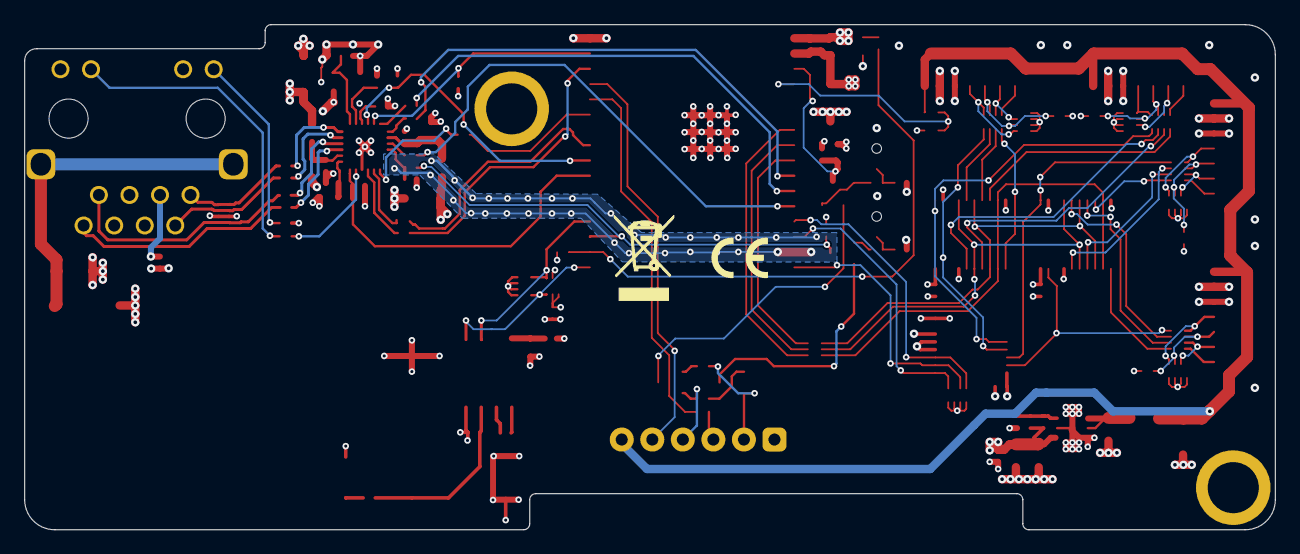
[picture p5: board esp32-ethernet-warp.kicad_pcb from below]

Board: 4 copper layers, 104.0 x 42.0 mm, 116 parts (3 on the bottom side), 106 nets.

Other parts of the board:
Fiducial_Mark: VAL**; Fiducial_Mark
Fiducial_Mark#2, Fiducial_Mark#3, Fiducial_Mark#4: VAL**; Fiducial_Mark
U202: TPD4S010DQA
VAL: WEEE_7mm
VAL#2: CE_5mm

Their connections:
GND: U202.3 (GND), U202.8 (GND); also elsewhere on the board
RXINx: U202.5 (IN4), U202.6 (NC); also elsewhere on the board
RXIPx: U202.4 (IN3), U202.7 (NC); also elsewhere on the board
TXONx: U202.2 (IN2), U202.9 (NC); also elsewhere on the board
TXOPx: U202.1 (IN1), U202.10 (NC); also elsewhere on the board

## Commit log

2024-01-12 move hardware files to correct git repo
    [bricklets.kicad_sch, esp32-ethernet-warp.kicad_pcb, esp32-ethernet-warp.kicad_sch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]
2024-01-12 Add hint that software can be found in esp32-firmware git
2024-02-01 mark C314 as DNP
    [bricklets.kicad_sch, esp32-ethernet-warp.kicad_pcb, esp32-ethernet-warp.kicad_sch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]

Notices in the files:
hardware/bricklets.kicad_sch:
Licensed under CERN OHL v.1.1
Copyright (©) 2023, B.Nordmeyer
